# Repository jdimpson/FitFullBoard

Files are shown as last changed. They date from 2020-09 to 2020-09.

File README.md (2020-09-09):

FitFullBoard is a Raspberry Pi- and Raspberry Pi Zero-compatible daughter board intended to power up and power down the the RPi board in sync with outside signals. 

I use it to keep an RPi media player powered along with my television. I connect the fitfullboard's signal pin called EXTERNAL to a USB cable which I plug into my smart teevee (but I power the RPi from an independent power source.) When the teevee comes on, it brings its USB port on, which wakes up the RPi. When the teevee goes off, it brings its USB port down, which puts the RPi to sleep (following a configurable grace period).  It is possible to turn the teevee back on at just the wrong time so as to get them out of sync (after the grace period expires, while the RPi operating system is still shutting down). 

Python software is available in the [RPiIoT](https://github.com/jdimpson/RPiIoT) repo.

FitFullBoard uses an ATtiny85 to control power up / power down and to monitor the EXTERNAL signal, and python code running in the RPi to handle shutdown and grace period. The grace period works because the ATtiny will hold the shutdown signal to the RPI down indefinitely. If the EXTERNAL signal comes back on, the ATtiny with bring the shutdown signal back high again. If this happens within the grace period, the python software will not initiate shutdown. You can instead use the Linux kernel's builtin signal handling for shutdown, althuogh AFAIK it has no way of offering a grace period.

Raspberry Pi Pins used:
- GPIO3/Phys5/SCL is used to power up the RPi. This only works if the RPi has been shut down via the "poweroff" or "shutdown" Linux commands. THe board itself must still have power.
- GPIO17/Phy11 is connected to a momentary / tactile switch. Available for arbitrary software control (typically running my powerboard.py and associated code).
- GPIO27/Phy13 is connected to a resistor and then an LED. Available for arbitrary software control (e.g. flashing to show grace period, and typically running my powerboard.py and associated code).
- GPIO26/Phy37 is connected via transistor and appropriate hold up resistor to the LBO/Shutdown pin of the ATtiny85. This is how the Raspberry Pi knows to shut down. This is labelled LBO and referred to as "Low Battery" in the schematic because the circuit and my python lowbattery code were reused from the PowerBoard (https://github.com/jdimpson/PowerBoard) and PowerHolder (https://github.com/jdimpson/PowerHolder) projects, in which when the Li Ion battery level fell below 3.4VDC (or whatever) the boards sent an LBO signal to the raspberry pi to shutdown, again with a grace period that allowed you to maybe plug it into external power (typically running my powerboard.py and associated code).

ATtiny85 pin used:
- PB0/MOSI used as RX for soft UART (for debugging, note the arduino code doesn't RX currently)
- PB1/MISO used as TX for soft UART (for debugging)
- PB2/SCK used to send the LBO/shutdown signal that tells the RPi to power off following a grace period.
- PB3 used to receive EXTERNAL signal (e.g. teevee power on indication). Circuit can be held up to 5VDC or down to ground, depending on which pads you put the resistor on (DON'T ATTACH BOTH R4 and R5 RESISTORS).
- PB4 is attached to a momentary / tactile button to allow manual start of the RPi independent of the EXTernal signal.

Other items of Note:
- I honestly don't remember why I called this the FitFullBoard. Something about the phrase "sleeping in fits and starts" being an analogue to automatically starting up and shutting down in response to an external influence. But honestly who knows? At one point I called it GraceFullBoard because it allowed for graceful shutdown of a raspberry pi in response to a signal. I should have kept that name.
- ATtiny85 code works with Arduino IDE and requires the https://github.com/SpenceKonde/ATTinyCore library.
- Python code referenced above will be posted and linked to soon.
- The use of GPIO3 to cause a shutdown RPi to restart does not seem to be well known. At least, it's not referenced on pinout.xyz (https://pinout.xyz/pinout/pin5_gpio3#). I've personally tested it to work on RPi Zero Ws, RPi 3B, and an RPi 4B with updated firmware. Note that this behaviour of GPIO3 is *different* from that of the RUN pin that is found in elsewhere on the board (not on the 40-pin header). The RUN pin will, when brought high, cause the RPi to reboot, even if the CPU is already running. This crashes the OS, which isn't something I want to do regularly. GPIO3 acts like any other pin when the CPU is running normally. It only seems to have special behaviour when the the CPU has halted following a graceful shutdown of the OS. When it gets brought high, it will cause a reboot. But *only* when the CPU was halted. See also https://www.raspberrypi.org/forums/viewtopic.php?t=113200 and https://www.raspberrypi.org/forums/viewtopic.php?p=767687#p767687

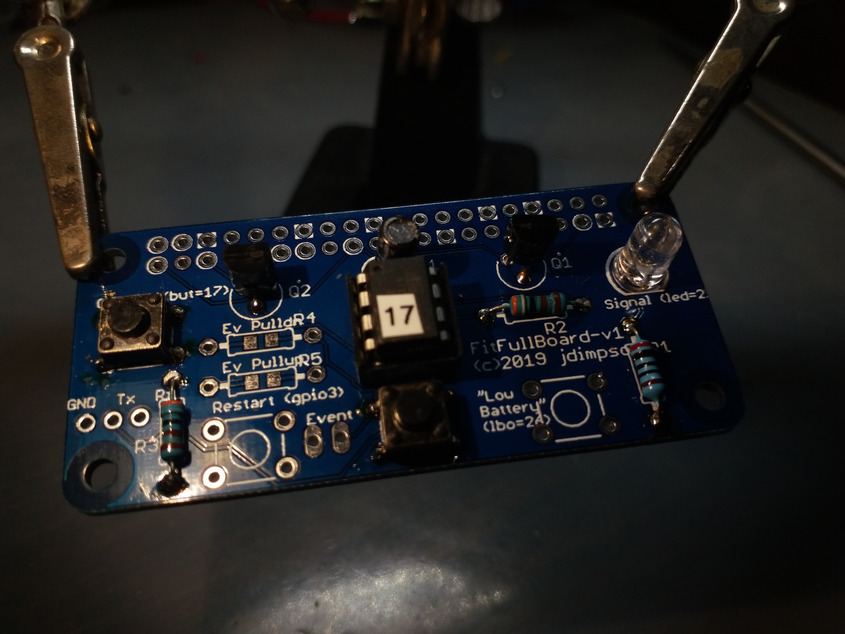
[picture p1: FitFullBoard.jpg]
Picture of board


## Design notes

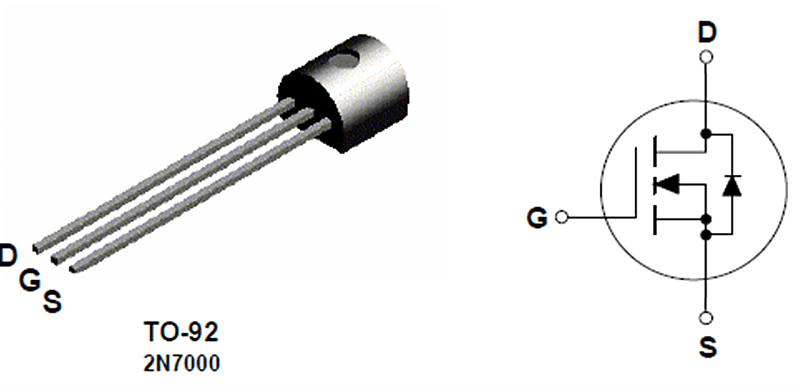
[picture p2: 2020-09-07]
FitFullBoard/2N7000.png

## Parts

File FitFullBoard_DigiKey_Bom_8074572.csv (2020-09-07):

Manufacturer Part Number | Manufacturer | Digi-Key Part Number | Customer Reference | Reference Designator | Packaging | Part Status | Quantity | Unit Price | Extended Price | Quantity Available | Mfg Std Lead Time | Description | RoHS Status | Lead Free Status | REACH Status
ATTINY85-20PU | Microchip Technology | ATTINY85-20PU-ND | U2 |  | Tube | Active | 1 | 1.20000 | $1.20 | 144 | 21 Weeks | IC MCU 8BIT 8KB FLASH 8DIP | ROHS3 Compliant | Lead free | REACH Unaffected
USP1H0R1MDD | Nichicon | 493-15992-ND | C1 |  | Bulk | Active | 1 | 0.35000 | $0.35 | 2591 | 15 Weeks | CAP ALUM 0.1UF 20% 50V RADIAL | ROHS3 Compliant | Lead free | REACH Unaffected
SFR2500001001FR500 | Vishay Beyschlag/Draloric/BC Components | PPC1.00KYCT-ND | R2,R3,R4/5 |  | Cut Tape (CT) | Active | 3 | 0.14000 | $0.42 | 23724 | 22 Weeks | RES 1K OHM 0.4W 1% AXIAL | ROHS3 Compliant | Lead free | Not Available
SFR2500001000FR500 | Vishay Beyschlag/Draloric/BC Components | PPC100YCT-ND | R1 |  | Cut Tape (CT) | Active | 1 | 0.14000 | $0.14 | 13597 | 22 Weeks | RES 100 OHM 0.4W 1% AXIAL | ROHS3 Compliant | Lead free | Not Available
2N7000-G | Microchip Technology | 2N7000-G-ND | Q1,Q2 |  | Bag | Active | 2 | 0.37000 | $0.74 | 2054 | 21 Weeks | MOSFET N-CH 60V 0.2A TO92-3 | ROHS3 Compliant | Lead free | REACH Unaffected
C503B-RAN-CZ0C0AA1 | Cree Inc. | C503B-RAN-CZ0C0AA1-ND | D1 |  | Bulk | Active | 1 | 0.15000 | $0.15 | 51470 | 4 Weeks | LED RED CLEAR 5MM ROUND T/H | RoHS Compliant | Lead free | Not Available

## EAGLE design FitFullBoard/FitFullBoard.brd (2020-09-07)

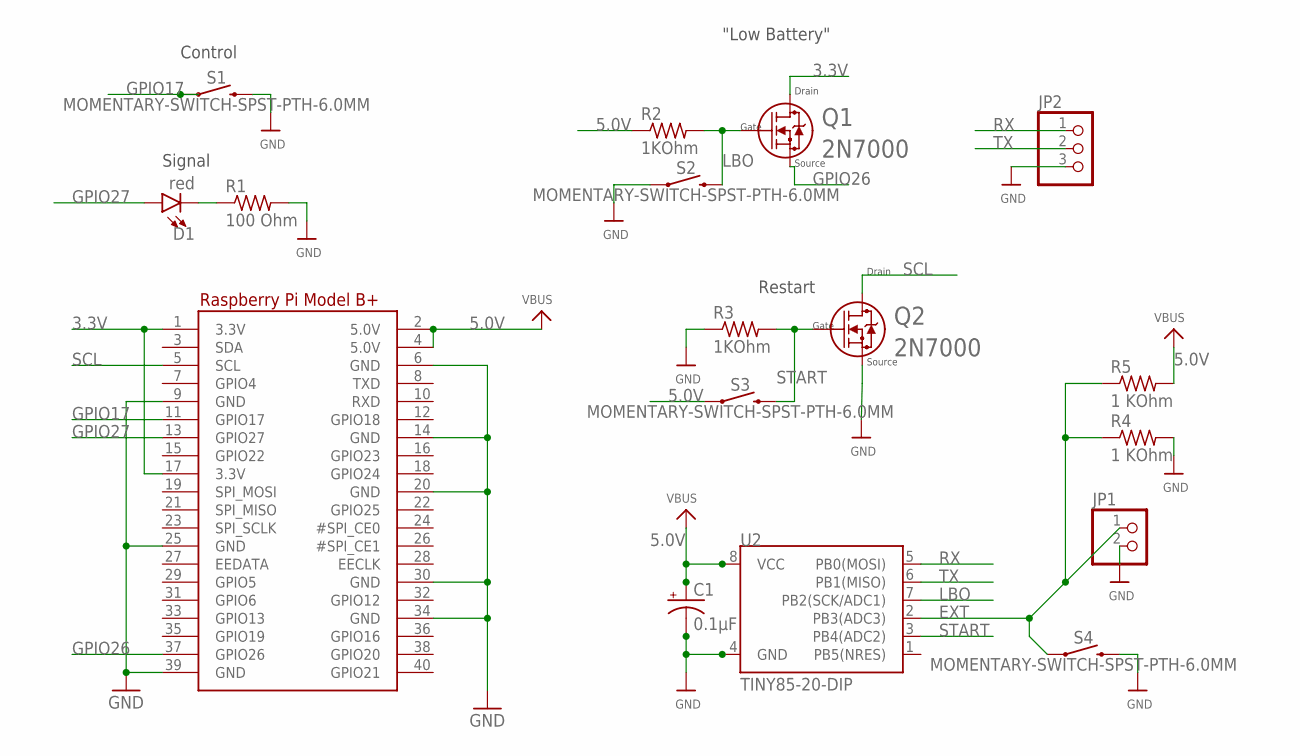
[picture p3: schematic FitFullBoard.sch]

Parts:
C1: 0.1µF; E2,5RE
D1: red; LED_5MM
JP1: HEADER-1X2; 1X02_OVAL
JP2: PINHD-1X3CB; 1X03-CLEANBIG
Q1, Q2: 2N7000; TO-92
R1: 100 Ohm; 0805-THM
R2, R3: 1KOhm; 0805-THM
R4, R5: 1 KOhm; 0805-THM
RPI1: RASPBERRYPI_BPLUS_BONNETNODIM; PI_BONNET_NODIM
S1, S2, S3, S4: MOMENTARY-SWITCH-SPST-PTH-6.0MM; TACTILE_SWITCH_PTH_6.0MM
U2: TINY85-20-DIP; DIP08_MCU

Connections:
3.3V: Q1.3 (2), RPI1.1 (3.3V), RPI1.17 (3.3V)
5.0V: C1.+, R2.1, R5.2, RPI1.2 (5.0V), RPI1.4 (5.0V), S3.1, U2.8 (VCC)
EXT: JP1.1, R4.1, R5.1, S4.1, U2.2 (PB3(ADC3))
GND: C1.-, JP1.2, JP2.3, Q2.1 (3), R1.2, R3.1, R4.2, RPI1.6 (GND), RPI1.9 (GND), RPI1.14 (GND), RPI1.20 (GND), RPI1.25 (GND), RPI1.30 (GND), RPI1.34 (GND), RPI1.39 (GND), S1.3 (2), S2.1, S4.3 (2), U2.4 (GND)
GPIO17: RPI1.11 (GPIO17), S1.1
GPIO26: Q1.1 (3), RPI1.37 (GPIO26)
GPIO27: D1.A, RPI1.13 (GPIO27)
LBO: Q1.2 (1), R2.2, S2.3 (2), U2.7 (PB2(SCK/ADC1))
unnamed: D1.K (C), R1.1
RX: JP2.1, U2.5 (PB0(MOSI))
SCL: Q2.3 (2), RPI1.5 (SCL)
START: Q2.2 (1), R3.2, S3.3 (2), U2.3 (PB4(ADC2))
TX: JP2.2, U2.6 (PB1(MISO))

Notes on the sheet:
Signal
Control
Source
Gate
"Low Battery"
Drain
Restart

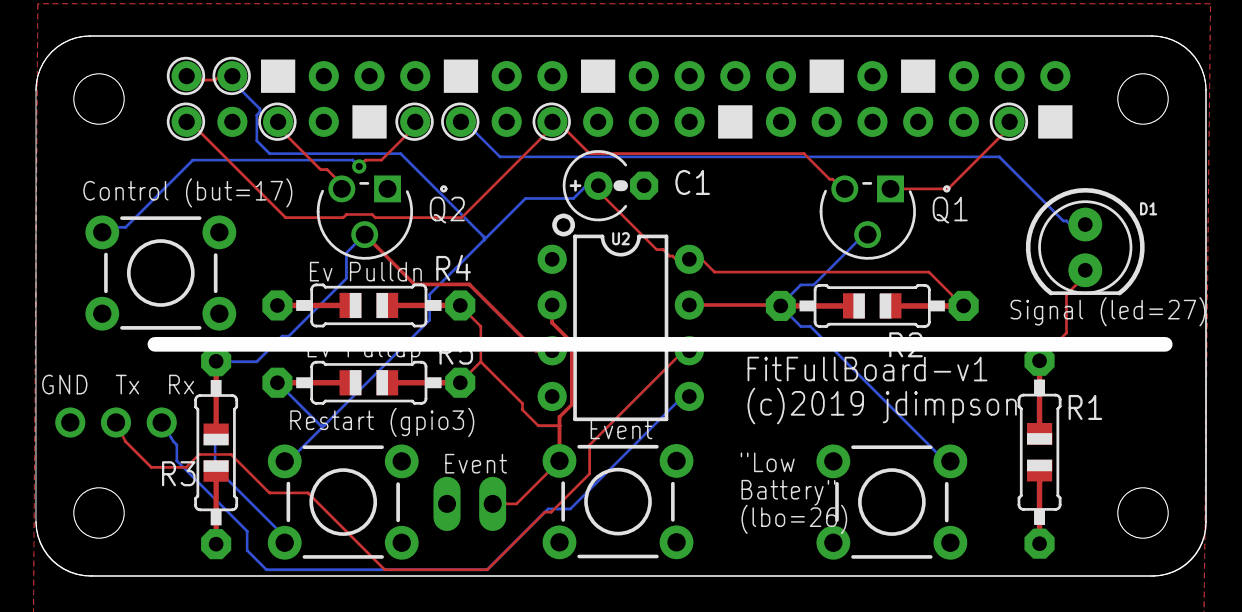
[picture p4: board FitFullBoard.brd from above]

Board: 2 copper layers, 65.0 x 30.0 mm, 17 parts (0 on the bottom side), 13 nets.

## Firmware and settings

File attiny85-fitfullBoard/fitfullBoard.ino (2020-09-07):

/**********************************************************************
 * ATTiny85 MCU monitors an external signal. When the signal (EXT) 
 * activates, MCU will bring RPi GPIO3 (START) low, which, if the RPi 
 * previously did a poweroff, will cause it to restart. At the same time, 
 * MCU will bring RPi GPIO26 (LBO) high. When the EXT signal deactivates, 
 * MCU will bring RPi GPIO26 (LBO) low.
 * 
 * The intention for the signal on GPIO26 is that the RPi runs software 
 * that treats it as a low-battery signal. When the software starts up, 
 * it looks at GPIO26. If high, it knows to use the pin as low-battery signal. 
 * (If low, don't monitor pin.) When GPIO26 goes low, RPi software will 
 * initiate a graceful shutdown.
 * 
 * Could probably do both the restart and LBO on GPIO3, but GPIO26 is used
 * for LBO due to commonality with my batter power boards.
 * 
 * Don't forget to level shift the LBO and START pins, assuming MCU is running 
 * at 5V.
 * 
 * (c) 2019 jdimpson
 **********************************************************************/

// NOTE: right now, the EXT signal must be HIGH for on, LOW for off. Would 
// be cool to use EEPROM to store the EXT signal mode, and adjust accordingly.

#include <SoftwareSerial.h>
#include <EEPROM.h>
#include "Debounce.h"

#define EXT   3 // Physical 2 / PB3 / A3
#define START 4 // Physical 3 / PB4
#define RX   -1 // Physical 5 / PB0; Reserved, not currently used. 
#define TX    1 // Physical 6 / PB1
#define LBO   2 // Physical 7 / PB2

#define OFF          0
#define STARTUP      1
#define SYNC_SIGNAL  2
#define HIGH_MONITOR 3
#define LOW_MONITOR  4

SoftwareSerial ss(RX, TX);
Debounce Button(EXT);

int state = STARTUP;
int prevstate = OFF;

void setup() {
  ss.begin(9600);
  ss.println(F("fitfullBoard"));
  ss.println(F(__FILE__));
  ss.print(F("compiled ")); 
  ss.println(__DATE__);
  delay(10);

  pinMode(EXT,INPUT);
  pinMode(LBO,OUTPUT);
  pinMode(START,INPUT); // leave high impedence

  ss.println("Waiting a second...");
  delay(1000);
  ss.println("Go!");
}

void loop() {
  state_machine(); 
}

inline void stay_awake() {
  if(digitalRead(LBO) != HIGH) {
    digitalWrite(LBO,HIGH);
  }
}

inline void wake_up() {
  pinMode(START,OUTPUT); // go low impedence
  digitalWrite(START,HIGH); // then go to high, which will switch the RPi's GPIO3 to ground via MOSFET
  delay(1000);
  pinMode(START,INPUT);// return to high impedence
}

inline void stay_sleep() {
  if(digitalRead(LBO) == HIGH) {
    digitalWrite(LBO,LOW);
  }
}

inline void stahp() {
  abort();
  // or assert(0); #include <assert.h> 
  // or set_sleep_mode(SLEEP_MODE_PWN_DOWN); cli(); sleep_mode(); #include <avr/sleep.h>
}

inline void state_machine() {
  bool delta = false;
  bool extsig = Button.read();

  if(state != prevstate) {
    delta = true;
    ss.print(prevstate);
    ss.print(F(" changed to "));
    ss.println(state);
    delay(50);
  }
  prevstate = state;
  //ss.print(F("extsig "));
  //ss.println(extsig);

  switch(state) {
    case STARTUP:
      state = SYNC_SIGNAL;
      stay_awake();
      break;

    case SYNC_SIGNAL:
      stay_awake();
      if(extsig) {
        state = HIGH_MONITOR;
      }
      break;

    case HIGH_MONITOR:
      if(delta) {
        wake_up();
      }
      stay_awake();
      if(!extsig) {
        state = LOW_MONITOR;
      }
      break;

    case LOW_MONITOR:
      stay_sleep();
      if(extsig) {
        state = HIGH_MONITOR;
      }
      break;

    default:
      ss.print("UNKNOWN STATE, ABORTING ");
      ss.println(state);
      delay(50);
      stahp();
      break;
  }

  delay(100);
}

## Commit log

2020-09-07 Added forgotten ATtiny pin PB4 description
2020-09-07 added arduino code
2020-09-07 Gerber files used to make some boards
2020-09-07 Bill of Materials from DigiKey
    [FitFullBoard_DigiKey_Bom_8074572.csv]
2020-09-09 picture of board

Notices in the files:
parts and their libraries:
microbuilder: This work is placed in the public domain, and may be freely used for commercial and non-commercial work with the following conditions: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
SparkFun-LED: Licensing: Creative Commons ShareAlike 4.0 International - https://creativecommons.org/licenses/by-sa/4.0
